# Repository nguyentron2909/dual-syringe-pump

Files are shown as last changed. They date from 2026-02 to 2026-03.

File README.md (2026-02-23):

# Dual Syringe Pump Controller (ESP32 + TMC2209)

This repository contains the KiCad hardware design for a compact, battery-powered dual stepper motor controller. Designed around the **ESP32-WROOM-32** for wireless control and **TMC2209** silent stepper drivers, this board is optimized for high-precision multi-channel micropump systems and drug delivery applications.

## 🛠 Hardware Architecture

The project is divided into three main functional blocks:

### 1. Power Management & Charging
A robust power subsystem designed to handle both wall power and battery operation, ensuring uninterrupted dispensing.
* **Charging:** Integrated **TP5100** battery charger for 2S Li-ion setups.
* **Regulation:** * **Buck Converter (LM2596):** Stepping down input voltage to 5V for logic.
    * **LDO (AMS1117-3.3):** Providing stable 3.3V for the ESP32 and sensors.
    * **Dual Boost Converters (XL6009):** Independent 12V rails (`+12V_1` and `+12V_2`) to power the stepper drivers, allowing for high-torque performance even on battery power.

### 2. Main Control & Interface
The logic center of the board, featuring:
* **MCU:** ESP32-WROOM-32 with USB-C programming via **CH340C** and an auto-reset circuit.
* **Position Feedback:** Support for dual **AS5600** magnetic encoders via I2C for closed-loop monitoring and exact position tracking.
* **User Interface:** Headers for an external screen, status LEDs, and additional tactile buttons.

### 3. Stepper Driver Stage
High-performance motor control featuring:
* **Drivers:** Dual **TMC2209-LA** drivers (U6 & U7).
* **Communication:** UART interface mapped to the ESP32 for advanced configuration (StealthChop, StallGuard, dynamic current limits).
* **Optimization:** Support for hardware-level current sensing. *(Note: RS resistors should be desoldered from the current sensing module for better performance, as noted in the schematic).*

Control schematics
Power circuits
drivers
---

## 📋 Key Specifications

| Component | Specification |
| :--- | :--- |
| **Microcontroller** | ESP32-WROOM-32 (Wi-Fi/BT) |
| **Stepper Drivers** | 2x TMC2209 (SilentStepStick style) |
| **Input Voltage** | +12V Adapter or 2S Li-ion Battery |
| **Logic Voltage** | 3.3V and 5V |
| **Sensors** | 2x AS5600 Magnetic Encoders |
| **USB Interface** | USB-C (CH340C) |

---

## 📂 PCB layout
PCB layout
---

## 📝 Design Notes

* **Current Sensing:** Ensure you desolder the RS resistors from the driver modules if you are using an external current sensing setup to avoid interference.
* **Thermal Management:** Provide adequate cooling (heatsinks/airflow) for the XL6009 boost converters and TMC2209 drivers if running the stepper motors at high continuous currents.
* **Big thanks to google gemini for writting this for me :D

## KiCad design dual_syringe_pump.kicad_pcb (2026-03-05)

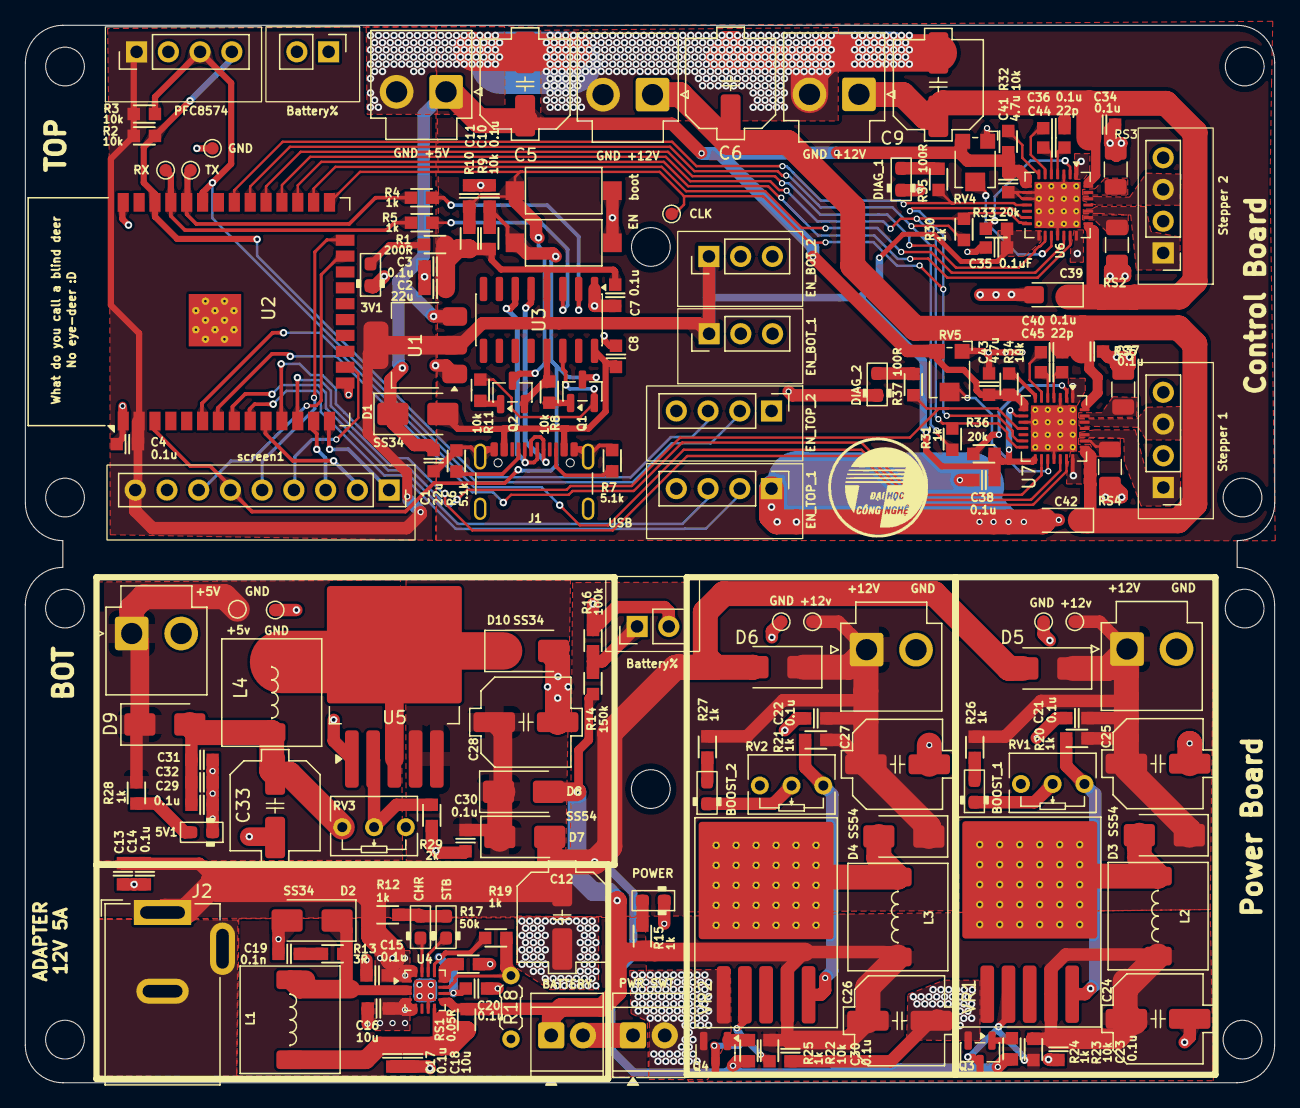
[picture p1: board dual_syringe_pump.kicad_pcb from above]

Board: 2 copper layers, 100.0 x 84.6 mm, 161 parts (0 on the bottom side), 97 nets.

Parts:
3V1, 5V1: LED; LED_0603_1608Metric_Pad1.05x0.95mm
+5V    GND: buck; JST_VH_B2P-VH-B_1x02_P3.96mm_Vertical
+12V     GND: boost_2; JST_VH_B2P-VH-B_1x02_P3.96mm_Vertical
+12V     GND#2: boost_1; JST_VH_B2P-VH-B_1x02_P3.96mm_Vertical
BATTERY: Bat_protected; TerminalBlock_TE_282834-2_1x02_P2.54mm_Horizontal
BOOST_1, BOOST_2: LED; LED_0603_1608Metric_Pad1.05x0.95mm
Battery%: battery _percentage; PinHeader_1x02_P2.54mm_Vertical
Battery%#2: battery _percentage; PinHeader_1x02_P2.54mm_Vertical
C1, C2: 22u; C_0603
C3, C4, C7, C10, C13, C15, C17, C20, C21, C22, C23, C30, C30#2, C31, C34, C36, C37, C38, C40: 0.1u; C_0603
C5, C6, C9, C12, C25, C27, C28, C33: 100uF; C_Elec_6.3x7.7
C8, C11, C14, C29, C32, C35: 0.1uF; C_0603
C16, C18: 10u; C_0603
C19: 0.1n; C_0603
C24, C26: 330uF; C_Elec_6.3x7.7
C39, C42: 100uF; CP_EIA-3216-12_Kemet-S_HandSolder
C41, C43: 4.7u; C_0603
C44, C45: 22p; C_0603
CHR: LED; LED_0603_1608Metric_Pad1.05x0.95mm
D1, D2, D9, D10: SS34; D_SMA
D3, D4, D5, D6, D7, D8: SS54; D_SMA
DIAG_1, DIAG_2: LED; LED_0603_1608Metric_Pad1.05x0.95mm
EN_BOT_1, EN_BOT_2: Conn_01x03; PinHeader_1x03_P2.54mm_Vertical
EN_TOP_1, EN_TOP_2: Conn_01x04; PinHeader_1x04_P2.54mm_Vertical
GND: TestPoint; TestPoint_Pad_D1.0mm
GND +5V: buck; JST_VH_B2P-VH-B_1x02_P3.96mm_Vertical
GND +12V: boost_2; JST_VH_B2P-VH-B_1x02_P3.96mm_Vertical
GND +12V#2: boost_1; JST_VH_B2P-VH-B_1x02_P3.96mm_Vertical
J1: USB_C_Receptacle_USB2.0_16P; USB_C_Receptacle_GCT_USB4105-xx-A_16P_TopMnt_Horizontal
J2: Barrel_Jack_Switch_Pin3Ring; BarrelJack_GCT_DCJ200-10-A_Horizontal
L1: 22uH; L_7.3x7.3_H4.5
L2, L3: 47uH; L_7.3x7.3_H4.5
L4: 33uH; L_7.3x7.3_H4.5
PFC8574: Conn_01x04; PinHeader_1x04_P2.54mm_Vertical
POWER: LED; LED_0603_1608Metric_Pad1.05x0.95mm
PWR SWT: pb; TerminalBlock_TE_282834-2_1x02_P2.54mm_Horizontal
Q1, Q2, Q3, Q4: SS8050; SOT-23
R1: 200R; R_0603
R2, R3, R8, R9, R10, R11, R22, R23, R32, R34: 10k; R_0603
R4, R5, R12, R15, R19, R20, R21, R24, R25, R26, R27, R28, R30, R31: 1k; R_0603
R6, R7: 5.1k; R_0603
R13: 3R; R_0603
R14: 150k; R_0603
R16: 100k; R_0603
R17: 50k; R_0603
R18: 47d 3950 (10K); R_Axial_DIN0204_L3.6mm_D1.6mm_P5.08mm_Horizontal
R29: 2k; R_0603
R33, R36: 20k; R_0603
R35, R37: 100R; R_0603
RS1: 0.05R; R_0603
RS2, RS3, RS4, RS5: 0.1R; R_1206_3216Metric
RV1, RV2, RV3: 10k; Potentiometer_Bourns_3266Y_Vertical
RV4, RV5: 20k; Potentiometer_Bourns_TC33X_Vertical
STB: LED; LED_0603_1608Metric_Pad1.05x0.95mm
SW1: boot; SW_SPST_CK_RS282G05A3
SW2: reset; SW_SPST_CK_RS282G05A3
Stepper 1, Stepper 2: Conn_01x04; PinHeader_1x04_P2.54mm_Vertical
TP1: clock; TestPoint_Pad_D1.0mm
TP2: rx; TestPoint_Pad_D1.0mm
TP3: tx; TestPoint_Pad_D1.0mm
TP4, TP5, TP6, TP7, TP8, TP9: TestPoint; TestPoint_Pad_D1.0mm
U1: AMS1117-3.3; SOT-223-3_TabPin2
U2: ESP32-WROOM-32
U3: CH340C; SOIC-16_3.9x9.9mm_P1.27mm
U4: TP5100; LQFN-16-1EP_3x3mm_P0.5mm_EP1.7x1.7mm
U5: XL4015; TO-263-5_TabPin3
U6, U7: TMC2209-LA; VQFN-28-1EP_5x5mm_P0.5mm_EP3.7x3.7mm_ThermalVias
VR1, VR2: XL6019; TO-263-5_TabPin6_ThermalVias
screen1: Conn_01x09_Pin; PinSocket_1x09_P2.54mm_Vertical

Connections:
+3.3V: C2.1, C3.1, C4.1, C7.1, C35.2, C38.2, EN_BOT_1.1, EN_BOT_2.1, PFC8574.1, R1.2, R2.1, R3.1, R9.1, R10.1, R33.1, R36.1, U1.2 (VO), U2.2 (VDD), U3.4 (V3), U6.15 (VCC_IO), U7.9 (MS1/AD0), U7.15 (VCC_IO), screen1.9
+5V: +5V GND.1, C1.1, C5.1, C41.2, C43.2, D1.1 (K), D9.1 (K), GND +5V.1, R28.2, R32.1, R34.1, RV4.3, RV5.3, TP8.1, U1.3 (VI), U6.8 (5VOUT), U7.8 (5VOUT)
+12V_1: +12V GND#2.1, C9.1, C21.1, C25.1, C34.1, C36.1, C39.1, D3.1 (K), D5.1 (K), GND +12V#2.1, R20.2, R26.2, TP4.1, U6.22 (VS), U6.28 (VS)
+12V_2: +12V GND.1, C6.1, C22.1, C27.1, C37.1, C40.1, C42.1, D4.1 (K), D6.1 (K), GND +12V.1, R21.2, R27.2, TP5.1, U7.22 (VS), U7.28 (VS)
/BACKLIGHT: U2.10 (IO25), screen1.2
/CS: U2.23 (IO15), screen1.7
/D+: J1.A6 (D+), J1.B6 (D+), U3.5 (UD+)
/D-: J1.A7 (D-), J1.B7 (D-), U3.6 (UD-)
/DC: U2.24 (IO2), screen1.5
/DTR: Q2.2 (E), R8.1, U3.13 (~DTR)
/MISO: U2.14 (IO12), screen1.1
/MOSI: U2.16 (IO13), screen1.4
/Power Circuits/FB: R29.2, RV3.2, U5.2 (FB)
/Power Circuits/NTC: R18.2 (-), R19.2, U4.11 (TS)
/Power Circuits/Vreg: C20.1, R19.1, U4.10 (VREG), U4.13 (CS)
/RST: Q1.2 (E), R11.2, U3.14 (~RTS)
/RX: R5.2, TP2.1, U2.35 (TXD0/IO1)
/SCK: U2.13 (IO14), screen1.3
/SCL: EN_TOP_2.3, PFC8574.4, R2.2, U2.36 (IO22)
/SCL1: EN_TOP_1.3, U2.8 (IO32)
/SDA: EN_TOP_2.2, PFC8574.3, R3.2, U2.33 (IO21)
/SDA1: EN_TOP_1.2, U2.9 (IO33)
/TX: R4.2, TP3.1, U2.34 (RXD0/IO3)
/esp_EN: C10.1, Q1.3 (C), R9.2, SW1.1, U2.3 (EN), screen1.6
Adapter_+12V: C12.1, C13.1, C14.1, C15.1, C16.1, D5.2 (A), D6.2 (A), D7.2 (A), J2.1, R12.1, R24.2, R25.2, U4.1 (VIN), U4.4 (VIN), U4.5 (VIN), U4.16 (VIN)
DIAG_1: R35.2, U2.31 (IO19), U6.11 (DIAG)
DIAG_2: R37.2, U2.12 (IO27), U7.11 (DIAG)
DIR_1: U2.26 (IO4), U6.19 (DIR)
DIR_2: U2.6 (IO34), U7.19 (DIR)
EN_1: U2.27 (IO16), U6.20 (STDBY)
EN_2: U2.11 (IO26), U7.20 (STDBY)
Earth: BATTERY.2 (-), C12.2, C13.2, C14.2, C15.2, C16.2, C17.2, C18.2, C19.2, C20.2, D2.2 (A), J2.2, J2.3, PWR SWT.1, R17.1, R18.1 (+), U4.7 (GND), U4.17 (EXP)
GND: 5V1.1 (K), +5V GND.2, +12V GND.2, +12V GND#2.2, BOOST_1.1 (K), BOOST_2.1 (K), Battery%.2, C21.2, C22.2, C23.2, C24.2, C25.2, C26.2, C27.2, C28.2, C29.2, C30.2, C30#2.2, C31.2, C32.2, C33.2, D10.2 (A), POWER.1 (K), PWR SWT.2, Q3.2 (E), Q4.2 (E), R16.2, R29.1, RV1.2, RV2.2, TP6.1, TP7.1, TP9.1, U5.1 (GND), VR1.1 (GND), VR2.1 (GND)
GND1: 3V1.1 (K), C1.2, C2.2, C3.2, C4.2, C5.2, C6.2, C7.2, C8.2, C9.2, C10.2, C11.2, C34.2, C35.1, C37.2, C38.1, C39.2, C41.1, C42.2, C43.1, DIAG_1.1 (K), DIAG_2.1 (K), EN_BOT_1.3, EN_BOT_2.3, EN_TOP_1.1, EN_TOP_2.1, GND.1, GND +5V.2, GND +12V.2, GND +12V#2.2, J1.A1 (GND), J1.A12 (GND), J1.B1 (GND), J1.B12 (GND), J1.S1 (SHIELD), PFC8574.2, R6.1, R7.2, RS2.2, RS3.2, RS4.2, RS5.2, RV4.1, RV5.1, SW1.2, SW2.2, U1.1 (GND), U2.1 (GND), U2.15 (GND), U2.38 (GND), U2.39 (GND), U3.1 (GND), U6.3 (GND), U6.9 (MS1/AD0), U6.10 (MS2/AD1), U6.18 (GND), U6.29 (GND), U7.3 (GND), U7.10 (MS2/AD1), U7.18 (GND), U7.29 (GND), screen1.8
unnamed: 3V1.2 (A), R1.1
unnamed: 5V1.2 (A), R28.1
unnamed: BOOST_1.2 (A), R26.1
unnamed: BOOST_2.2 (A), R27.1
unnamed: C19.1, R13.1
unnamed: CHR.2 (A), R12.2, STB.2 (A)
unnamed: CHR.1 (K), U4.15 (~CHRG)
unnamed: D2.1 (K), L1.1, R13.2, U4.2 (LX), U4.3 (LX)
unnamed: D3.2 (A), L2.2, VR1.3 (SW), VR1.6 (SW)
unnamed: D4.2 (A), L3.2, VR2.3 (SW), VR2.6 (SW)
unnamed: C28.1, C30.1, D7.1 (K), D8.1 (K), U5.4 (VC), U5.5 (VIN)
unnamed: C29.1, C31.1, C32.1, C33.1, D9.2 (A), L4.2, RV3.1
unnamed: D10.1 (K), L4.1, U5.3 (SW)
unnamed: DIAG_1.2 (A), R35.1
unnamed: DIAG_2.2 (A), R37.1
unnamed: J1.A5 (CC1), R6.2
unnamed: J1.B5 (CC2), R7.1
unnamed: Q1.1 (B), R8.2
unnamed: Q2.1 (B), R11.1
unnamed: Q3.1 (B), R24.1
unnamed: Q3.3 (C), R23.2, VR1.2 (EN)
unnamed: Q4.1 (B), R25.1
unnamed: Q4.3 (C), R22.2, VR2.2 (EN)
unnamed: STB.1 (K), U4.14 (~STDBY)
unnamed: Stepper 2.1, U6.24 (OA1)
unnamed: Stepper 2.2, U6.21 (OA2)
unnamed: Stepper 2.3, U6.26 (OB1)
unnamed: Stepper 2.4, U6.1 (OB2)
unnamed: Stepper 1.1, U7.24 (OA1)
unnamed: Stepper 1.2, U7.21 (OA2)
unnamed: Stepper 1.3, U7.26 (OB1)
unnamed: Stepper 1.4, U7.1 (OB2)
unnamed: R5.1, U3.3 (RXD)
unnamed: R4.1, U3.2 (TXD)
unnamed: R17.2, U4.12 (RTRICK)
unnamed: C17.1, C18.1, L1.2, RS1.2, U4.8 (VS)
unnamed: RS2.1, U6.23 (BRA)
unnamed: RS3.1, U6.27 (BRB)
unnamed: C44.2, U6.5 (CPI)
unnamed: C44.1, U6.4 (CPO)
unnamed: R32.2, U6.7 (SPREAD)
unnamed: C36.2, U6.6 (VCP)
unnamed: RV4.2, U6.17 (VREF)
unnamed: R33.2, U6.2 (~EN)
unnamed: RS4.1, U7.23 (BRA)
unnamed: RS5.1, U7.27 (BRB)
unnamed: C45.2, U7.5 (CPI)
unnamed: C45.1, U7.4 (CPO)
unnamed: R34.2, U7.7 (SPREAD)
unnamed: C40.2, U7.6 (VCP)
unnamed: RV5.2, U7.17 (VREF)
unnamed: R36.2, U7.2 (~EN)
unnamed: R20.1, RV1.3, VR1.5 (FB)
unnamed: R21.1, RV2.3, VR2.5 (FB)
unnamed: POWER.2 (A), R15.1
unnamed: Battery%.1, R14.2, R16.1
RX_TMC: R30.2, R31.2, U2.28 (IO17), U6.14 (~PD/UART), U7.14 (~PD/UART)
STEP_1: U2.29 (IO5), U6.16 (STEP)
STEP_2: U2.7 (IO35), U7.16 (STEP)
TX_TMC: R30.1, R31.1, U2.30 (IO18)
USB_5V: C8.1, D1.2 (A), J1.A4 (VBUS), J1.A9 (VBUS), J1.B4 (VBUS), J1.B9 (VBUS), U3.16 (VCC)
Vbat: BATTERY.1 (+), C23.1, C24.1, C26.1, C30#2.1, D8.2 (A), L2.1, L3.1, R14.1, R15.2, R22.1, R23.1, RS1.1, U4.9 (BAT), VR1.4 (VIN), VR2.4 (VIN)
esp32_CLK: C11.1, Q2.3 (C), R10.2, SW2.1, TP1.1, U2.25 (IO0), U6.13 (CLK), U7.13 (CLK)

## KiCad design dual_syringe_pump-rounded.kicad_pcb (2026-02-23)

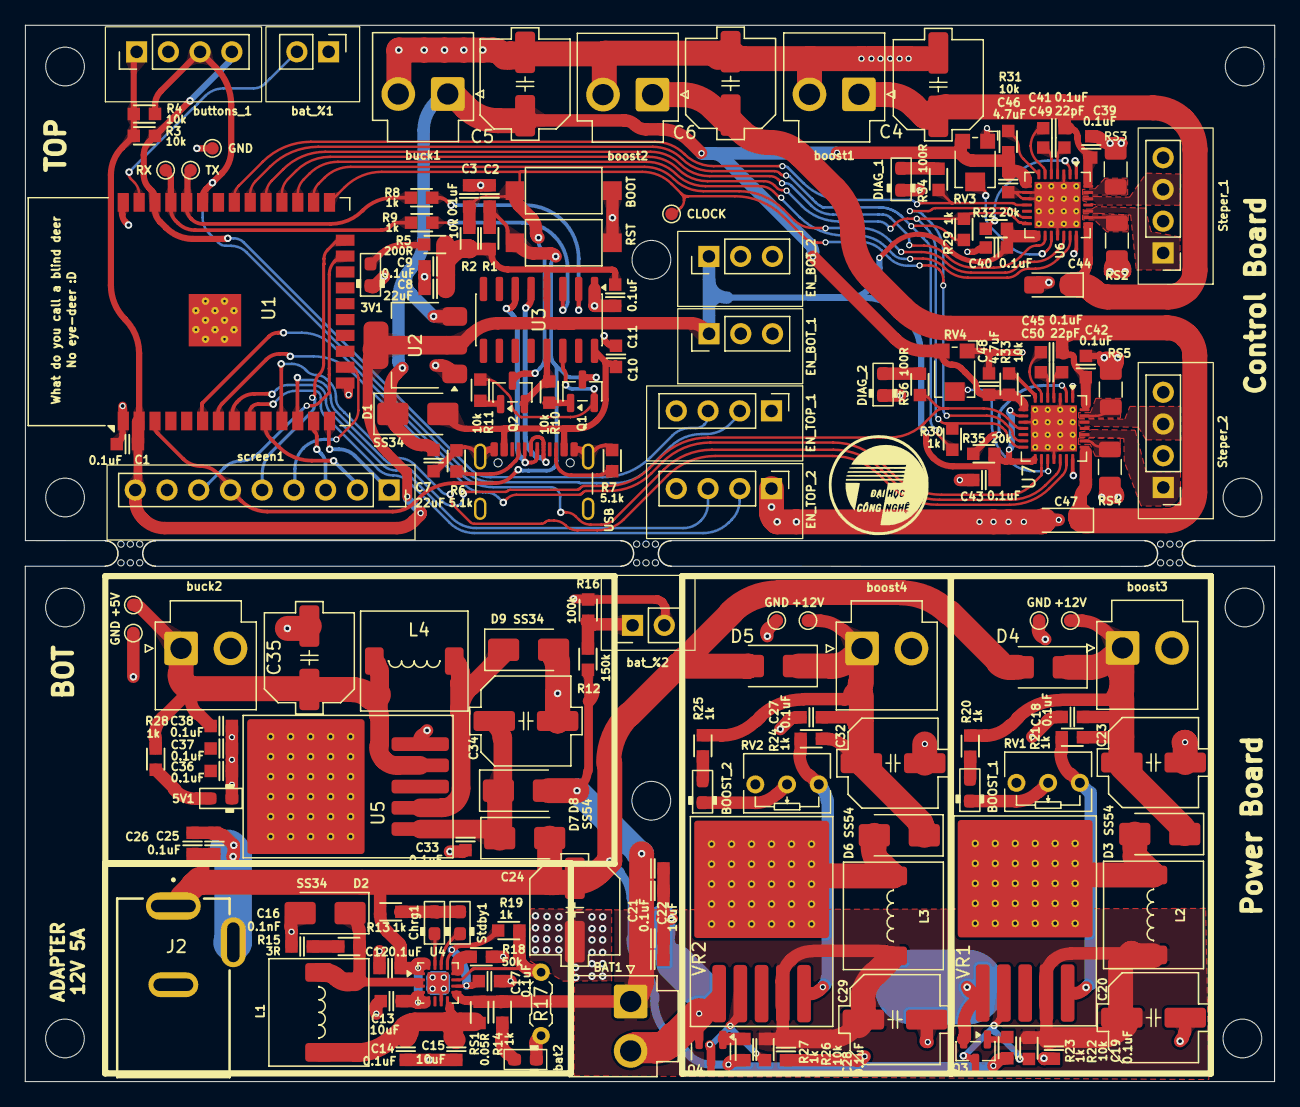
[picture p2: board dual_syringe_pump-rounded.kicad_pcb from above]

Board: 2 copper layers, 100.0 x 84.6 mm, 164 parts (0 on the bottom side), 95 nets.

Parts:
3V1, 5V1: LED; LED_0603_1608Metric_Pad1.05x0.95mm
+5V, +12V, +12V#2: TestPoint; TestPoint_Pad_D1.0mm
BAT1: Bat_protected; JST_VH_B2P-VH-B_1x02_P3.96mm_Vertical
BOOST_1, BOOST_2: LED; LED_0603_1608Metric_Pad1.05x0.95mm
BOOT: reset; SW_SPST_CK_RS282G05A3
C1, C2, C3, C9, C10, C11, C12, C14, C17, C18, C19, C21, C25, C26, C27, C28, C30, C33, C36, C37, C38, C39, C40, C41, C42, C43, C45: 0.1uF; C_0603
C4, C5, C6, C23, C24, C32, C34, C35: 100uF; C_Elec_6.3x7.7
C7, C8: 22uF; C_0603
C13, C15, C22, C31: 10uF; C_0603
C16: 0.1nF; C_0603
C20, C29: 330uF; C_Elec_6.3x7.7
C44, C47: 100uF; CP_EIA-3216-12_Kemet-S_HandSolder
C46, C48: 4.7uF; C_0603
C49, C50: 22pF; C_0603
CLOCK: TestPoint; TestPoint_Pad_D1.0mm
Chrg1: LED; LED_0603_1608Metric_Pad1.05x0.95mm
D1, D2, D9: SS34; D_SMA
D3, D4, D5, D6, D7, D8: SS54; D_SMA
DIAG_1, DIAG_2: LED; LED_0603_1608Metric_Pad1.05x0.95mm
EN_BOT_1, EN_BOT_2: Conn_01x03; PinHeader_1x03_P2.54mm_Vertical
EN_TOP_1, EN_TOP_2: Conn_01x04; PinHeader_1x04_P2.54mm_Vertical
GND: TestPoint; TestPoint_Pad_D1.0mm
GND#2, GND#3, GND#4: TestPoint; TestPoint_Pad_D1.0mm
J2: Barrel_Jack_Switch_Pin3Ring; GCT_DCJ200-10-A-XX-K_REVA
L1: 22uH; L_7.3x7.3_H4.5
L2, L3: 47uH; L_7.3x7.3_H4.5
L4: 33uH; L_7.3x7.3_H4.5
Q1, Q2, Q3, Q4: SS8050; SOT-23
R1, R2, R3, R4, R10, R11, R22, R26, R31, R33: 10k; R_0603
R5: 200R; R_0603
R6, R7: 5.1k; R_0603
R8, R9, R13, R14, R19, R20, R21, R23, R24, R25, R27, R28, R29, R30: 1k; R_0603
R12: 150k; R_0603
R15: 3R; R_0603
R16: 100k; R_0603
R17: 47d 3950 (10K); R_Axial_DIN0204_L3.6mm_D1.6mm_P5.08mm_Horizontal
R18: 50k; R_0603
R32, R35: 20k; R_0603
R34, R36: 100R; R_0603
RS1: 0.05R; R_0603
RS2, RS3, RS4, RS5: 0.1R; R_1206_3216Metric
RST: boot; SW_SPST_CK_RS282G05A3
RV1, RV2: 10k; Potentiometer_Bourns_3266Y_Vertical
RV3, RV4: 20k; Potentiometer_Bourns_TC33X_Vertical
RX: TestPoint; TestPoint_Pad_D1.0mm
Stdby1: LED; LED_0603_1608Metric_Pad1.05x0.95mm
Steper_1, Steper_2: Conn_01x04; PinHeader_1x04_P2.54mm_Vertical
TX: TestPoint; TestPoint_Pad_D1.0mm
U1: ESP32-WROOM-32
U2: AMS1117-3.3; SOT-223-3_TabPin2
U3: CH340C; SOIC-16_3.9x9.9mm_P1.27mm
U4: TP5100; LQFN-16-1EP_3x3mm_P0.5mm_EP1.7x1.7mm
U5: LM2596S-buck; TO-263-5_TabPin3_ThermalVias
U6, U7: TMC2209-LA; VQFN-28-1EP_5x5mm_P0.5mm_EP3.7x3.7mm_ThermalVias
USB: USB_C_Receptacle_USB2.0_16P; USB_C_Receptacle_GCT_USB4105-xx-A_16P_TopMnt_Horizontal
VR1, VR2: XL6019; TO-263-5_TabPin6_ThermalVias
bat2: LED; LED_0603_1608Metric_Pad1.05x0.95mm
bat_%1, bat_%2: battery _percentage; PinHeader_1x02_P2.54mm_Vertical
boost1, boost3: boost_1; JST_VH_B2P-VH-B_1x02_P3.96mm_Vertical
boost2, boost4: boost_2; JST_VH_B2P-VH-B_1x02_P3.96mm_Vertical
buck1, buck2: buck; JST_VH_B2P-VH-B_1x02_P3.96mm_Vertical
buttons_1: Conn_01x04; PinHeader_1x04_P2.54mm_Vertical
mouse-bite-2mm-slot, mouse-bite-2mm-slot#2, mouse-bite-2mm-slot#3: VAL**; mouse-bite-2mm-slot
screen1: Conn_01x09_Pin; PinSocket_1x09_P2.54mm_Vertical

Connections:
+3.3V: C1.1, C8.1, C9.1, C11.1, C40.2, C43.2, EN_BOT_1.1, EN_BOT_2.1, R1.1, R2.1, R3.1, R4.1, R5.2, R32.1, R35.1, U1.2 (VDD), U2.2 (VO), U3.4 (V3), U6.15 (VCC_IO), U7.9 (MS1/AD0), U7.15 (VCC_IO), buttons_1.1, screen1.9
+5V: +5V.1, C5.1, C7.1, C35.1, C36.1, C37.1, C38.1, C46.2, C48.2, D1.1 (K), L4.2, R28.2, R31.1, R33.1, RV3.3, RV4.3, U2.3 (VI), U5.4 (FB), U6.8 (5VOUT), U7.8 (5VOUT), buck1.1, buck2.1
+12V_1: +12V#2.1, C4.1, C18.1, C23.1, C39.1, C41.1, C44.1, D3.1 (K), D4.1 (K), R20.2, R21.2, U6.22 (VS), U6.28 (VS), boost1.1, boost3.1
+12V_2: +12V.1, C6.1, C27.1, C32.1, C42.1, C45.1, C47.1, D5.1 (K), D6.1 (K), R24.2, R25.2, U7.22 (VS), U7.28 (VS), boost2.1, boost4.1
/BACKLIGHT: U1.10 (IO25), screen1.2
/BTN1: U1.37 (IO23), bat_%1.2
/CS: U1.23 (IO15), screen1.7
/D+: U3.5 (UD+), USB.A6 (D+), USB.B6 (D+)
/D-: U3.6 (UD-), USB.A7 (D-), USB.B7 (D-)
/DC: U1.24 (IO2), screen1.5
/DTR: Q2.2 (E), R10.1, U3.13 (~DTR)
/MISO: U1.14 (IO12), screen1.1
/MOSI: U1.16 (IO13), screen1.4
/Power Circuits/NTC: R17.2 (-), R19.2, U4.11 (TS)
/Power Circuits/Vreg: C17.1, R19.1, U4.10 (VREG), U4.13 (CS)
/RST: Q1.2 (E), R11.2, U3.14 (~RTS)
/RX: R9.2, RX.1, U1.35 (TXD0/IO1)
/SCK: U1.13 (IO14), screen1.3
/SCL: EN_TOP_1.3, R3.2, U1.36 (IO22), buttons_1.4
/SCL1: EN_TOP_2.3, U1.8 (IO32)
/SDA: EN_TOP_1.2, R4.2, U1.33 (IO21), buttons_1.3
/SDA1: EN_TOP_2.2, U1.9 (IO33)
/TX: R8.2, TX.1, U1.34 (RXD0/IO3)
/esp_EN: C2.1, Q1.3 (C), R1.2, RST.1, U1.3 (EN), screen1.6
Adapter_+12V: C12.1, C13.1, C24.1, C25.1, C26.1, D4.2 (A), D5.2 (A), D7.2 (A), J2.1, R13.1, R23.2, R27.2, U4.1 (VIN), U4.4 (VIN), U4.5 (VIN), U4.16 (VIN)
DIAG_1: R34.2, U1.31 (IO19), U6.11 (DIAG)
DIAG_2: R36.2, U1.12 (IO27), U7.11 (DIAG)
DIR_1: U1.26 (IO4), U6.19 (DIR)
DIR_2: U1.6 (IO34), U7.19 (DIR)
EN_1: U1.27 (IO16), U6.20 (STDBY)
EN_2: U1.11 (IO26), U7.20 (STDBY)
GND: 5V1.1 (K), BAT1.2 (-), BOOST_1.1 (K), BOOST_2.1 (K), C12.2, C13.2, C14.2, C15.2, C16.2, C17.2, C18.2, C19.2, C20.2, C21.2, C22.2, C23.2, C24.2, C25.2, C26.2, C27.2, C28.2, C29.2, C30.2, C31.2, C32.2, C33.2, C34.2, C35.2, C36.2, C37.2, C38.2, D2.2 (A), D9.2 (A), GND#2.1, GND#3.1, GND#4.1, J2.2, J2.3, Q3.2 (E), Q4.2 (E), R16.2, R17.1 (+), R18.1, RV1.2, RV2.2, U4.7 (GND), U4.17 (EXP), U5.3 (GND), U5.5 (~ON/OFF), VR1.1 (GND), VR2.1 (GND), bat2.1 (K), bat_%2.2, boost3.2, boost4.2, buck2.2
GND1: 3V1.1 (K), BOOT.2, C1.2, C2.2, C3.2, C4.2, C5.2, C6.2, C7.2, C8.2, C9.2, C10.2, C11.2, C39.2, C40.1, C42.2, C43.1, C44.2, C46.1, C47.2, C48.1, DIAG_1.1 (K), DIAG_2.1 (K), EN_BOT_1.3, EN_BOT_2.3, EN_TOP_1.1, EN_TOP_2.1, GND.1, R6.1, R7.2, RS2.2, RS3.2, RS4.2, RS5.2, RST.2, RV3.1, RV4.1, U1.1 (GND), U1.15 (GND), U1.38 (GND), U1.39 (GND), U2.1 (GND), U3.1 (GND), U6.3 (GND), U6.9 (MS1/AD0), U6.10 (MS2/AD1), U6.18 (GND), U6.29 (GND), U7.3 (GND), U7.10 (MS2/AD1), U7.18 (GND), U7.29 (GND), USB.A1 (GND), USB.A12 (GND), USB.B1 (GND), USB.B12 (GND), USB.S1 (SHIELD), bat_%1.1, boost1.2, boost2.2, buck1.2, buttons_1.2, screen1.8
unnamed: 3V1.2 (A), R5.1
unnamed: 5V1.2 (A), R28.1
unnamed: BOOST_1.2 (A), R20.1
unnamed: BOOST_2.2 (A), R25.1
unnamed: C16.1, R15.1
unnamed: Chrg1.2 (A), R13.2, Stdby1.2 (A)
unnamed: Chrg1.1 (K), U4.15 (~CHRG)
unnamed: D2.1 (K), L1.1, R15.2, U4.2 (LX), U4.3 (LX)
unnamed: D3.2 (A), L2.2, VR1.3 (SW), VR1.6 (SW)
unnamed: D6.2 (A), L3.2, VR2.3 (SW), VR2.6 (SW)
unnamed: C33.1, C34.1, D7.1 (K), D8.1 (K), U5.1 (VIN)
unnamed: D9.1 (K), L4.1, U5.2 (OUT)
unnamed: DIAG_1.2 (A), R34.1
unnamed: DIAG_2.2 (A), R36.1
unnamed: R6.2, USB.A5 (CC1)
unnamed: R7.1, USB.B5 (CC2)
unnamed: Q1.1 (B), R10.2
unnamed: Q2.1 (B), R11.1
unnamed: Q3.1 (B), R23.1
unnamed: Q3.3 (C), R22.1, VR1.2 (EN)
unnamed: Q4.1 (B), R27.1
unnamed: Q4.3 (C), R26.1, VR2.2 (EN)
unnamed: Stdby1.1 (K), U4.14 (~STDBY)
unnamed: Steper_1.1, U6.24 (OA1)
unnamed: Steper_1.2, U6.21 (OA2)
unnamed: Steper_1.3, U6.26 (OB1)
unnamed: Steper_1.4, U6.1 (OB2)
unnamed: Steper_2.1, U7.24 (OA1)
unnamed: Steper_2.2, U7.21 (OA2)
unnamed: Steper_2.3, U7.26 (OB1)
unnamed: Steper_2.4, U7.1 (OB2)
unnamed: R9.1, U3.3 (RXD)
unnamed: R8.1, U3.2 (TXD)
unnamed: R18.2, U4.12 (RTRICK)
unnamed: C14.1, C15.1, L1.2, RS1.2, U4.8 (VS)
unnamed: RS2.1, U6.23 (BRA)
unnamed: RS3.1, U6.27 (BRB)
unnamed: C49.2, U6.5 (CPI)
unnamed: C49.1, U6.4 (CPO)
unnamed: R31.2, U6.7 (SPREAD)
unnamed: C41.2, U6.6 (VCP)
unnamed: RV3.2, U6.17 (VREF)
unnamed: R32.2, U6.2 (~EN)
unnamed: RS4.1, U7.23 (BRA)
unnamed: RS5.1, U7.27 (BRB)
unnamed: C50.2, U7.5 (CPI)
unnamed: C50.1, U7.4 (CPO)
unnamed: R33.2, U7.7 (SPREAD)
unnamed: C45.2, U7.6 (VCP)
unnamed: RV4.2, U7.17 (VREF)
unnamed: R35.2, U7.2 (~EN)
unnamed: R21.1, RV1.3, VR1.5 (FB)
unnamed: R24.1, RV2.3, VR2.5 (FB)
unnamed: R14.1, bat2.2 (A)
unnamed: R12.2, R16.1, bat_%2.1
RX_TMC: R29.2, R30.2, U1.28 (IO17), U6.14 (~PD/UART), U7.14 (~PD/UART)
STEP_1: U1.29 (IO5), U6.16 (STEP)
STEP_2: U1.7 (IO35), U7.16 (STEP)
TX_TMC: R29.1, R30.1, U1.30 (IO18)
USB_5V: C10.1, D1.2 (A), U3.16 (VCC), USB.A4 (VBUS), USB.A9 (VBUS), USB.B4 (VBUS), USB.B9 (VBUS)
Vbat: BAT1.1 (+), C19.1, C20.1, C21.1, C22.1, C28.1, C29.1, C30.1, C31.1, D8.2 (A), L2.1, L3.1, R12.1, R14.2, R22.2, R26.2, RS1.1, U4.9 (BAT), VR1.4 (VIN), VR2.4 (VIN)
esp32_CLK: BOOT.1, C3.1, CLOCK.1, Q2.3 (C), R2.2, U1.25 (IO0), U6.13 (CLK), U7.13 (CLK)

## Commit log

2026-02-22 added mousebite to rounded PCB
    [dual_syringe_pump-rounded.kicad_pcb]
2026-02-22 Add README for Dual Syringe Pump Controller project
    Added detailed documentation for the Dual Syringe Pump Controller project, including hardware architecture, specifications, project structure, and design notes.
2026-02-22 Fix image path for PCB layout in README
    typo ffs
2026-02-22 Update - 22-Feb-26
    [battery_charger.kicad_sch, dual_syringe_pump-rounded.kicad_pcb]
2026-02-23 added power button
    [battery_charger.kicad_sch, dual_syringe_pump-rounded.kicad_pcb, dual_syringe_pump.kicad_pcb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]
2026-02-24 changed star gnd
    [dual_syringe_pump.kicad_pcb]
2026-03-05 changed silk screen, added grid for star ground
    [battery_charger.kicad_sch, dual_syringe_pump.kicad_pcb]
